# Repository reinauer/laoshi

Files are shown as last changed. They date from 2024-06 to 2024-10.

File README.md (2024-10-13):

# Project Laoshi (老師)

This is a simple ROM bank switcher for certain Amiga ROMs that allows switching between two ROM banks through reads from the host side.

There are three versions for your heart's delight: An SMD version, a through hole version, and a flat version to fit in space limited devices like the A590:

## Through Hole
<p float="center">
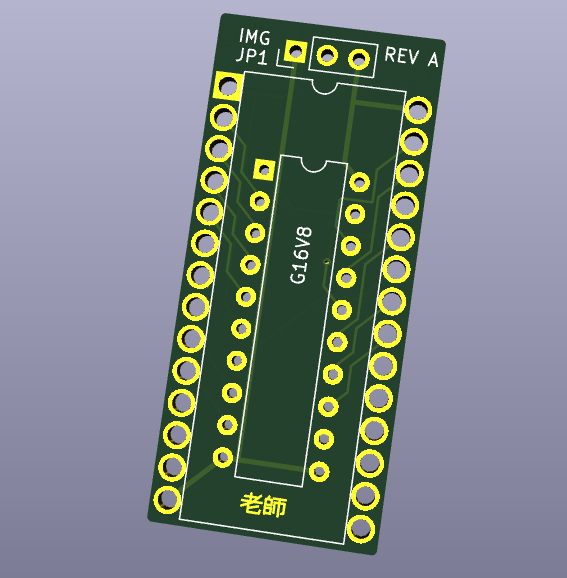
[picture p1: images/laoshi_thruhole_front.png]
  
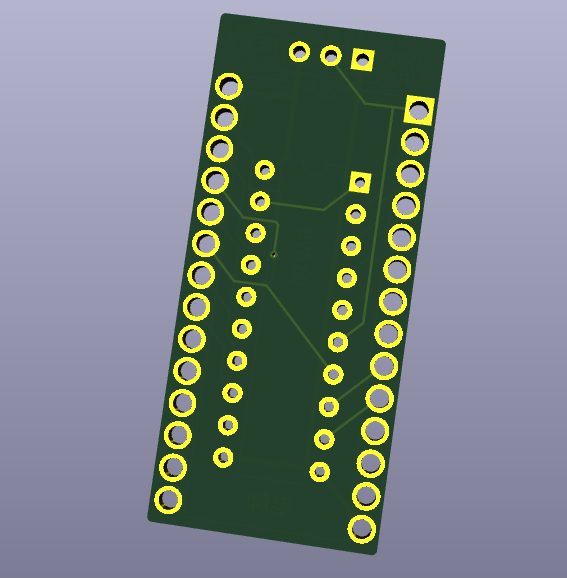
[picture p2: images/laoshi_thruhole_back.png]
  
</p>

## SMD
<p float="center">
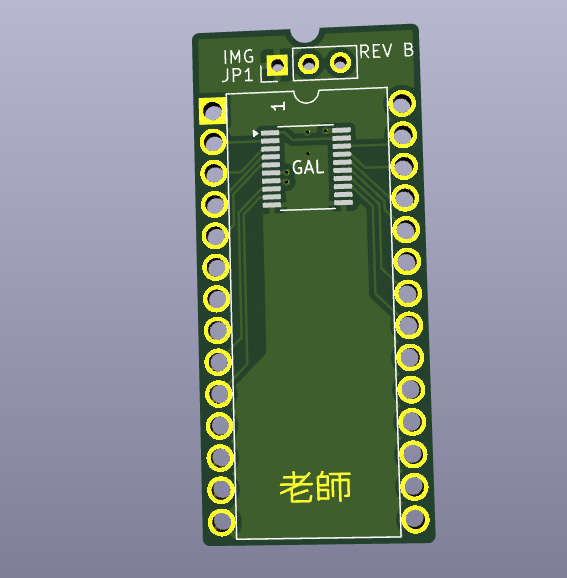
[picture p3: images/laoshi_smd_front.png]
  
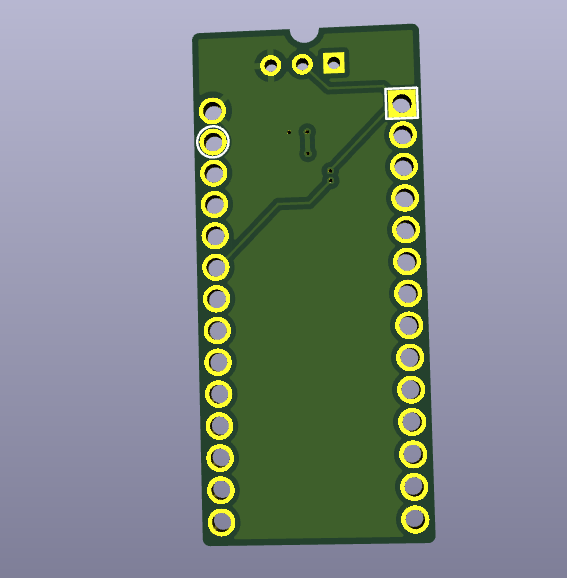
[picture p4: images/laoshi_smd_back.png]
  
</p>

## A590
<p float="center">
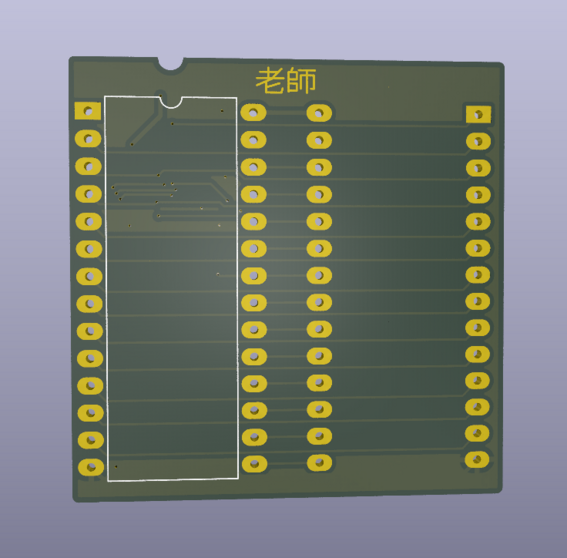
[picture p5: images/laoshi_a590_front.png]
  
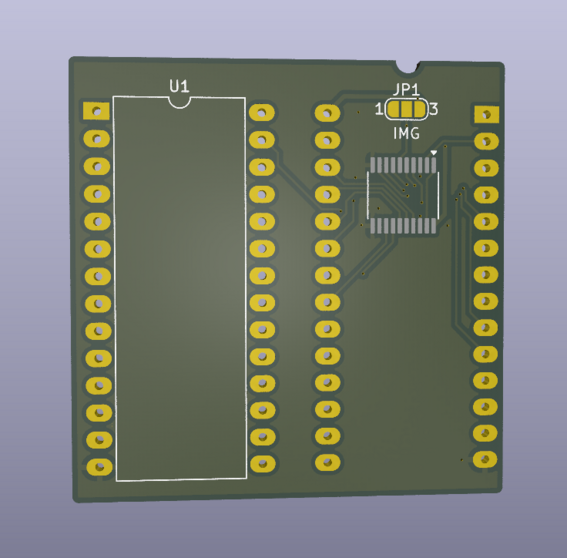
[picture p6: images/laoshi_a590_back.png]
  
</p>

# Implementation / BOM

Gerbers will be in each subdirectory under hardware. An ATF16V8 is needed
(either through hole or TSSOP) and should be programmed with laoshi.pld which
can be found under logic/

During assembly you need to cut pins 1 and 27 of the ROM socket.

When assembling the A590 version, don't use a socket for the flash chip. It is
also recommended to cut the pins of the pin headers flat to the PCB surface
before soldering, and covering the top with kapton tape to prevent shorts.

# Example pictures

## Through Hole version
<p float=center">
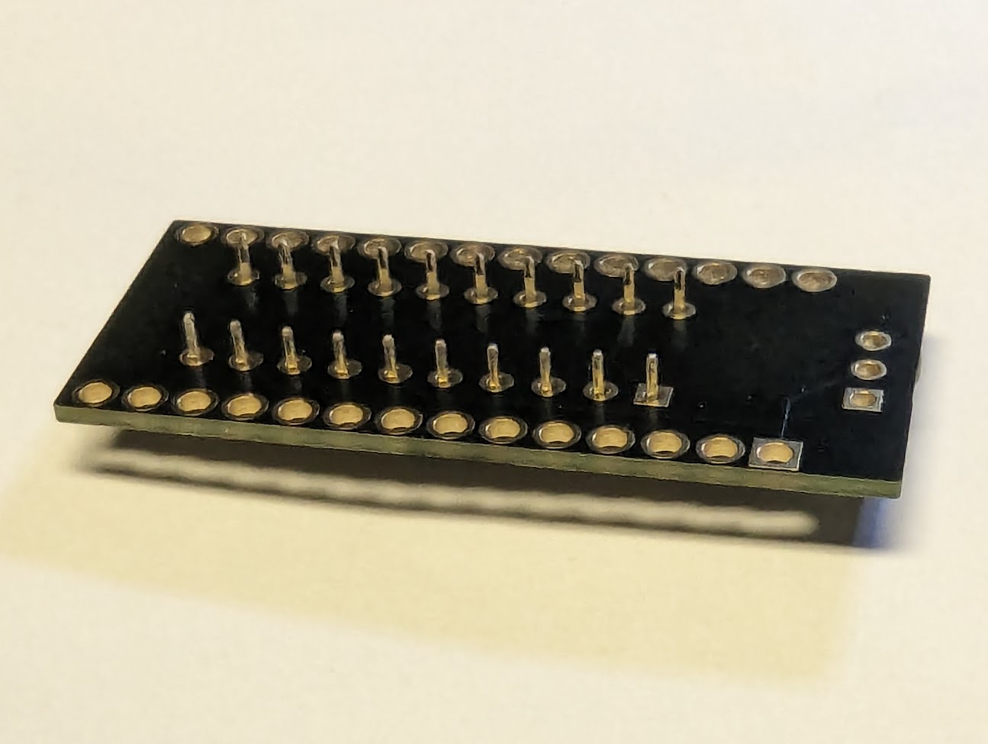
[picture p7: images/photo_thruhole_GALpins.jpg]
  
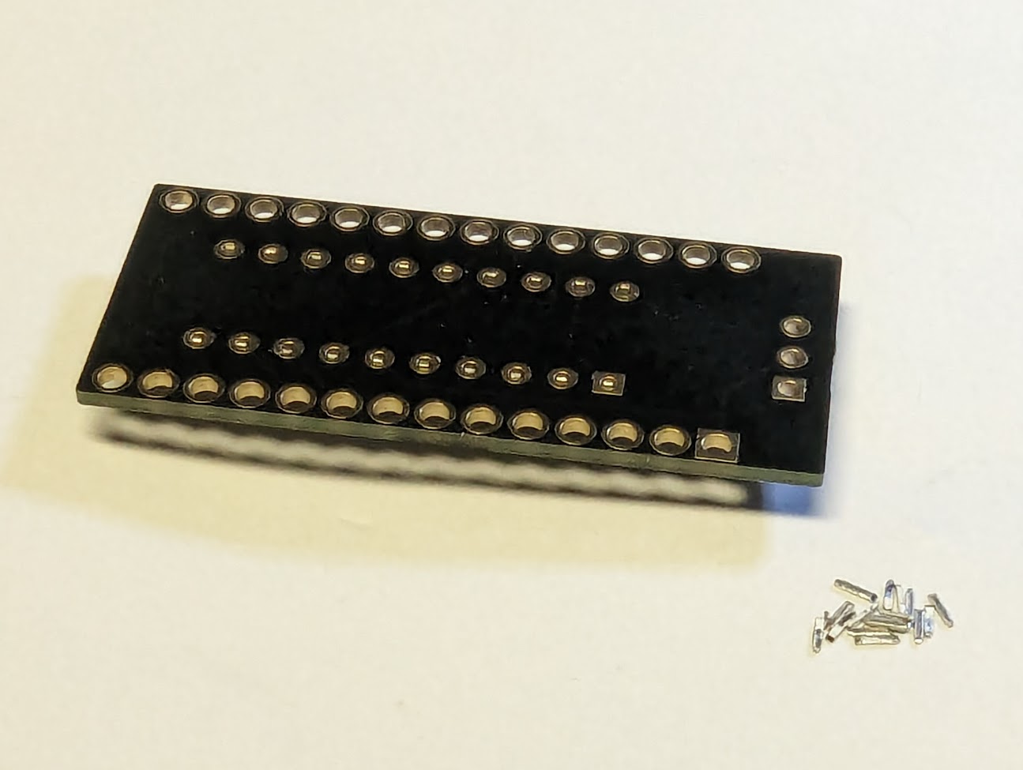
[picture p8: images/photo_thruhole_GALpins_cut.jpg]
  
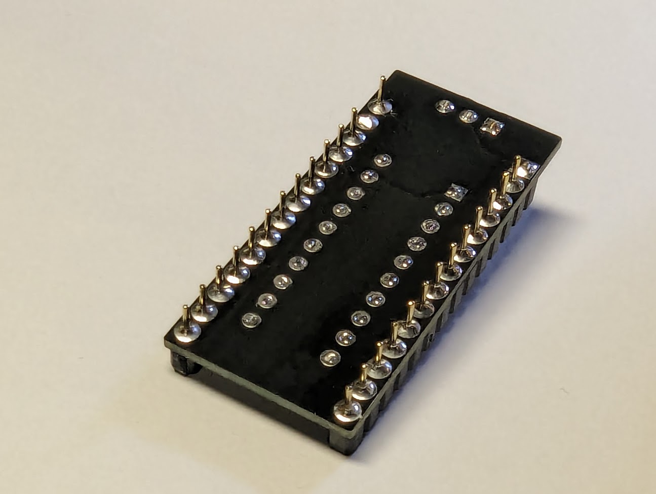
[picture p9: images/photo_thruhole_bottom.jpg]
  
</p>

## A590 version
<p float=center">
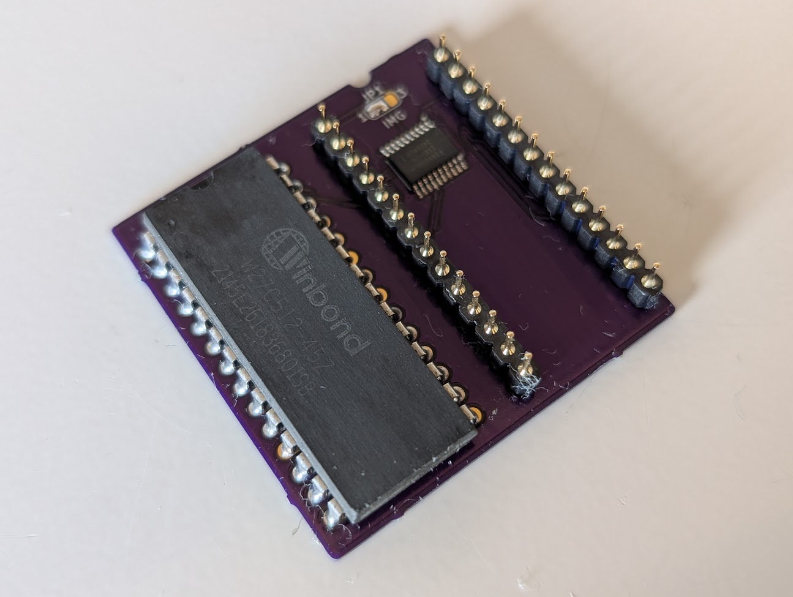
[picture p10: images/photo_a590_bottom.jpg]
  
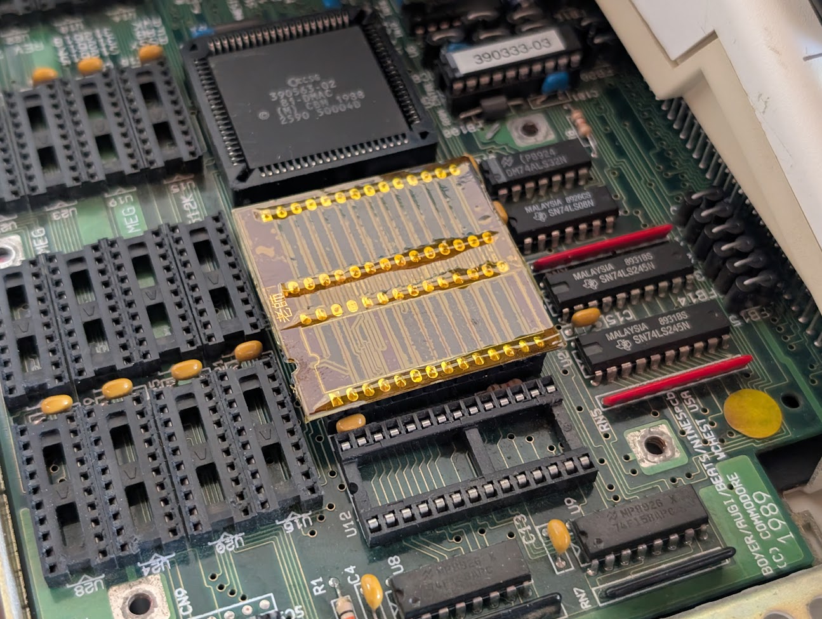
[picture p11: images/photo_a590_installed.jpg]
  
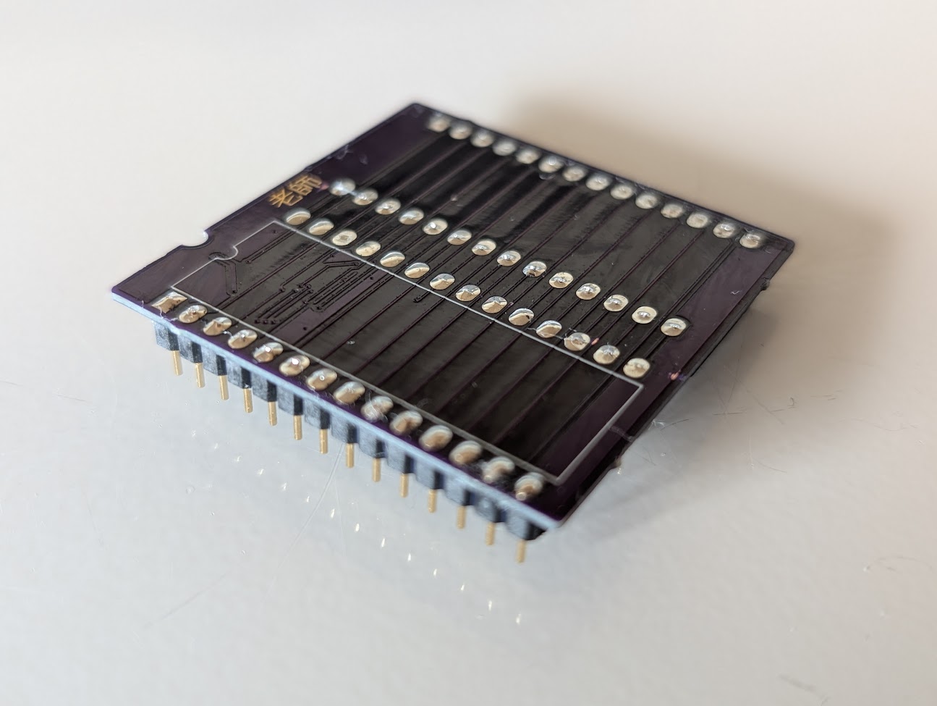
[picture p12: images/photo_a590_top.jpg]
  
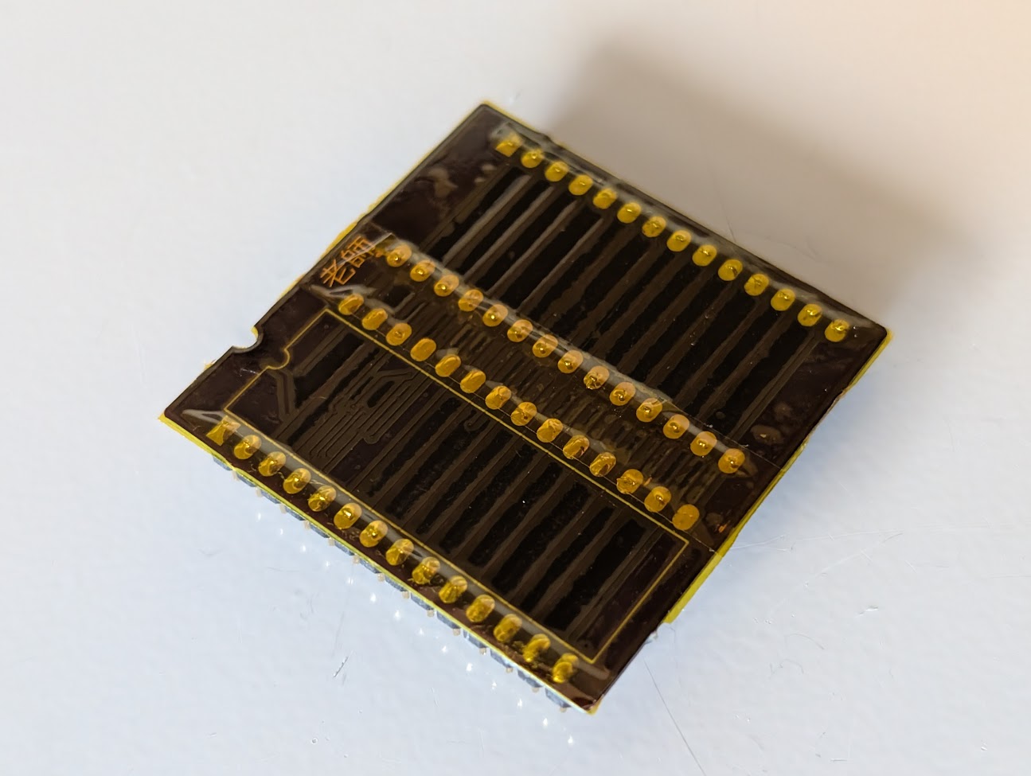
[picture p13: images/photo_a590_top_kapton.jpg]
  
</p>

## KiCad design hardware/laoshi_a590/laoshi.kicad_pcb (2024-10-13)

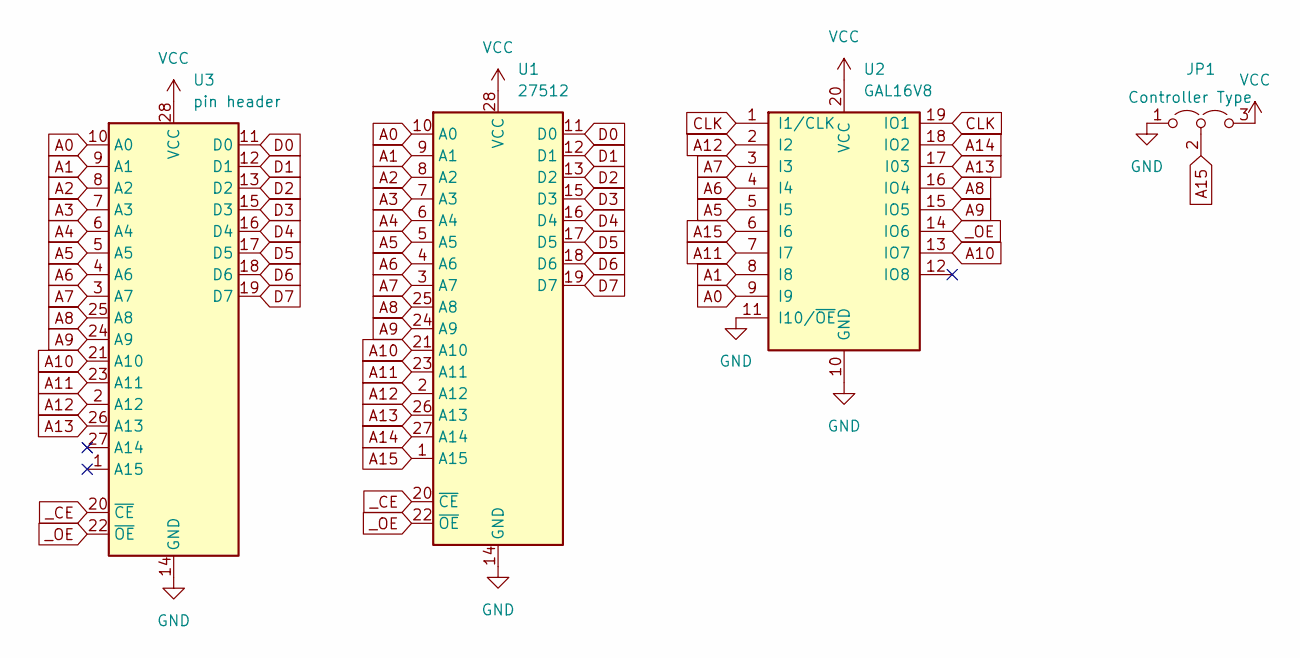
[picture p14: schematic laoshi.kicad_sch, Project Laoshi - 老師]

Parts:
JP1: Controller Type; SolderJumper-3_P1.3mm_Open_RoundedPad1.0x1.5mm_NumberLabels
U1: 27512; DIP-28_W15.24mm_LongPads
U2: GAL16V8; TSSOP-20_4.4x6.5mm_P0.65mm
U3: pin header; DIP-28_W15.24mm_LongPads

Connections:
A0: U1.10 (A0), U2.9 (I9), U3.10 (A0)
A1: U1.9 (A1), U2.8 (I8), U3.9 (A1)
A2: U1.8 (A2), U3.8 (A2)
A3: U1.7 (A3), U3.7 (A3)
A4: U1.6 (A4), U3.6 (A4)
A5: U1.5 (A5), U2.5 (I5), U3.5 (A5)
A6: U1.4 (A6), U2.4 (I4), U3.4 (A6)
A7: U1.3 (A7), U2.3 (I3), U3.3 (A7)
A8: U1.25 (A8), U2.16 (IO4), U3.25 (A8)
A9: U1.24 (A9), U2.15 (IO5), U3.24 (A9)
A10: U1.21 (A10), U2.13 (IO7), U3.21 (A10)
A11: U1.23 (A11), U2.7 (I7), U3.23 (A11)
A12: U1.2 (A12), U2.2 (I2), U3.2 (A12)
A13: U1.26 (A13), U2.17 (I03), U3.26 (A13)
A14: U1.27 (A14), U2.18 (IO2)
A15: JP1.2 (C), U1.1 (A15), U2.6 (I6)
CLK: U2.1 (I1/CLK), U2.19 (IO1)
D0: U1.11 (D0), U3.11 (D0)
D1: U1.12 (D1), U3.12 (D1)
D2: U1.13 (D2), U3.13 (D2)
D3: U1.15 (D3), U3.15 (D3)
D4: U1.16 (D4), U3.16 (D4)
D5: U1.17 (D5), U3.17 (D5)
D6: U1.18 (D6), U3.18 (D6)
D7: U1.19 (D7), U3.19 (D7)
GND: JP1.1 (A), U1.14 (GND), U2.10 (GND), U2.11 (I10/~OE), U3.14 (GND)
VCC: JP1.3 (B), U1.28 (VCC), U2.20 (VCC), U3.28 (VCC)
_CE: U1.20 (~CE), U3.20 (~CE)
_OE: U1.22 (~OE), U2.14 (IO6), U3.22 (~OE)

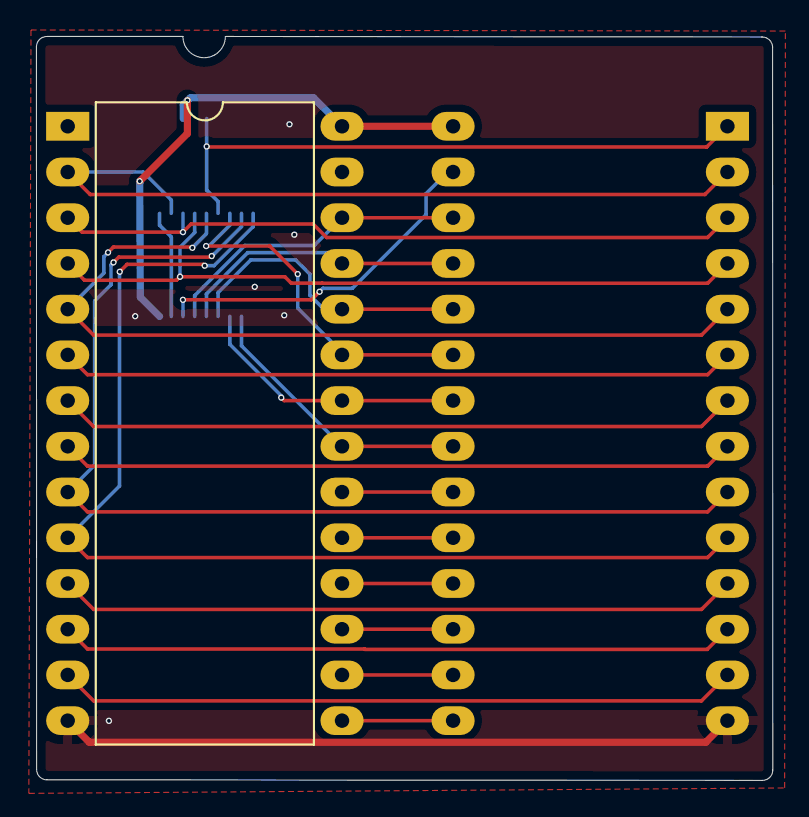
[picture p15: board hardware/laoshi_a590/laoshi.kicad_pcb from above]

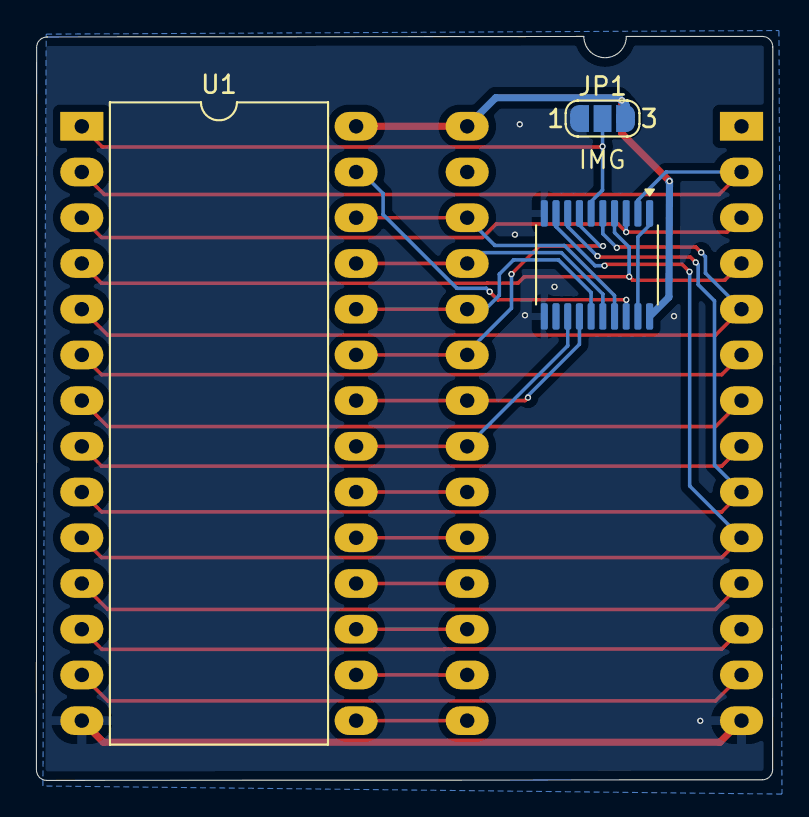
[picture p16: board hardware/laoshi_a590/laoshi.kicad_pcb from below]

Board: 2 copper layers, 40.9 x 41.3 mm, 4 parts (3 on the bottom side), 29 nets.

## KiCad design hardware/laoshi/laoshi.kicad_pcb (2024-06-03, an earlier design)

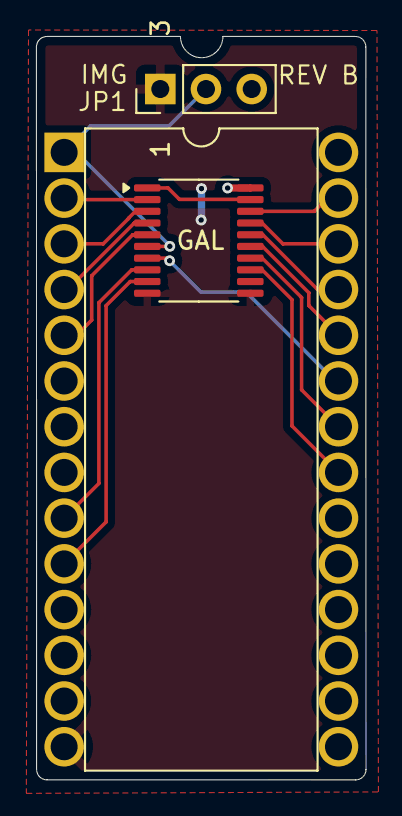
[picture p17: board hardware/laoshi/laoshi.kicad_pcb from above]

Board: 2 copper layers, 18.3 x 41.3 mm, 3 parts (0 on the bottom side), 17 nets.

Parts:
JP1: Image; PinHeader_1x03_P2.54mm_Vertical
U1: 27512; DIP-28_W15.24mm
U2: GAL16V8; TSSOP-20_4.4x6.5mm_P0.65mm

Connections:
A0: U1.10 (A0), U2.9 (I9)
A1: U1.9 (A1), U2.8 (I8)
A5: U1.5 (A5), U2.5 (I5)
A6: U1.4 (A6), U2.4 (I4)
A7: U1.3 (A7), U2.3 (I3)
A8: U1.25 (A8), U2.16 (IO4)
A9: U1.24 (A9), U2.15 (IO5)
A10: U1.21 (A10), U2.13 (IO7)
A11: U1.23 (A11), U2.7 (I7)
A12: U1.2 (A12), U2.2 (I2)
A13: U1.26 (A13), U2.17 (I03)
A14: U1.27 (A14), U2.18 (IO2)
A15: JP1.2 (C), U1.1 (A15), U2.6 (I6)
CLK: U2.1 (I1/CLK), U2.19 (IO1)
GND: JP1.1 (A), U1.14 (GND), U2.10 (GND), U2.11 (I10/~OE)
VCC: JP1.3 (B), U1.28 (VCC), U2.20 (VCC)
_OE: U1.22 (~OE), U2.14 (IO6)

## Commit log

2024-06-03 Add Through Hole version of Laoshi
    [laoshi.kicad_pcb, laoshi.kicad_sch]
2024-06-03 Add SMD version of Laoshi
    [laoshi.kicad_pcb, laoshi.kicad_sch]
2024-10-13 Add a super low footprint version
    [laoshi.kicad_pcb, laoshi.kicad_sch]
2024-10-13 Add pictures of assembled PCBs
2024-10-13 Add gerbers for a590 version
2024-10-14 Gerbers for TH version
